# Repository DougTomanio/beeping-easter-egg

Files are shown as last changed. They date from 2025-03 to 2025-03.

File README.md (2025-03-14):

# Beeping Easter Egg 🥚🔊

<p float="center">
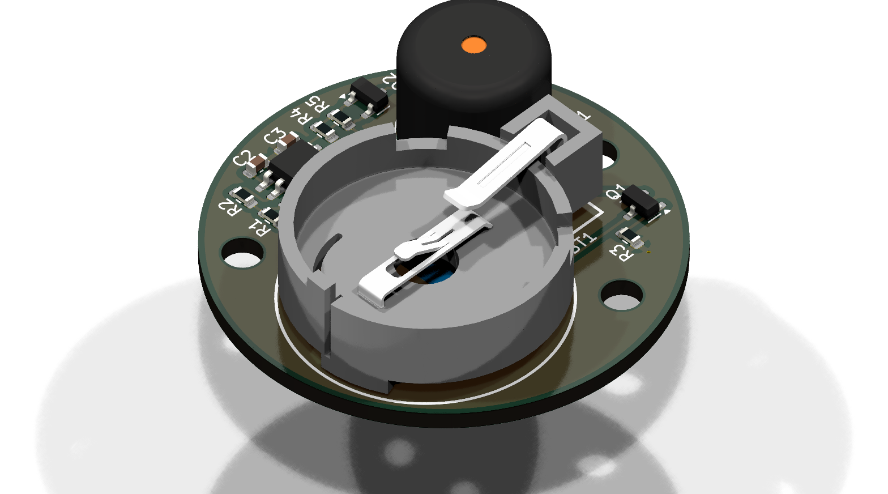
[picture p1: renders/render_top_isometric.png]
  
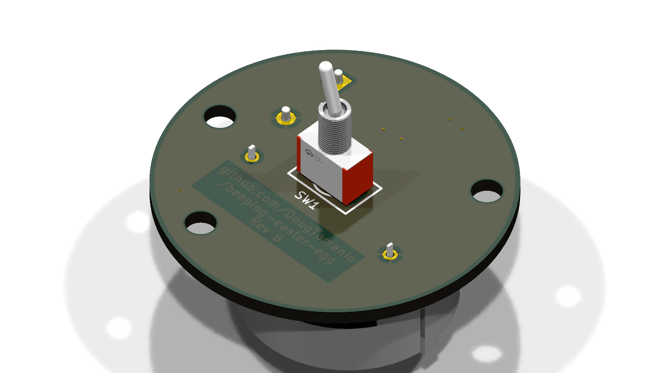
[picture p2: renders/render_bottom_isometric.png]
  
</p>
<p float="center">
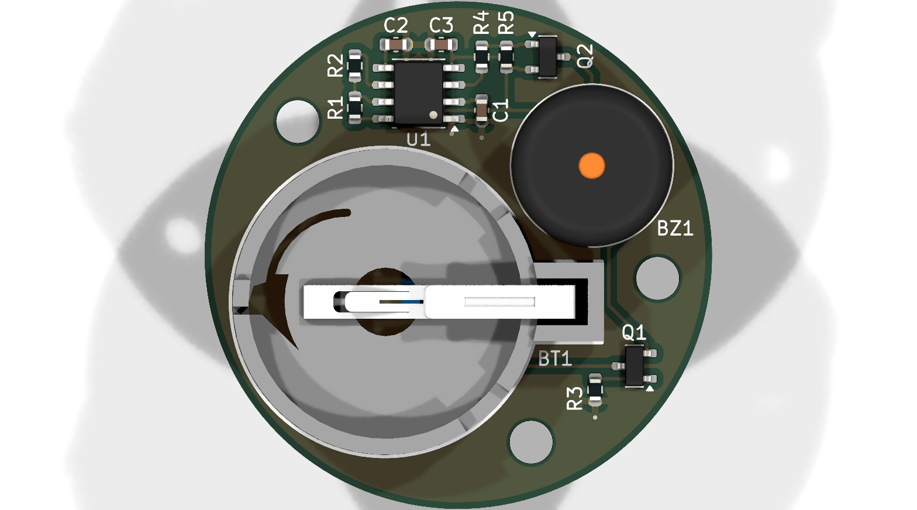
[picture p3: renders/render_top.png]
   
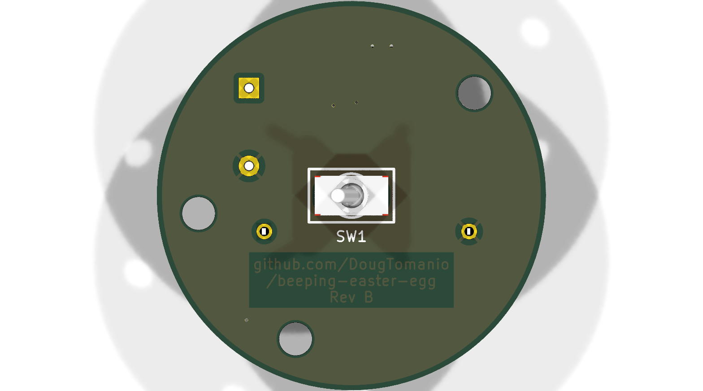
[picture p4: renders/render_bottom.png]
  
</p>


## Generate fabrication files
```
docker run --rm -v ${PWD}:/app -e COLS=5 -e ROWS=5 kicad/kicad:9.0 bash /app/scripts/generate-fabrication-files.sh
```

## Generate render pngs and schematic svg
```
docker run --rm -v ${PWD}:/app kicad/kicad:9.0 bash /app/scripts/generate-renders-for-readme.sh
```

## KiCad plugins / tools / scripts
* https://github.com/yaqwsx/KiKit
* https://github.com/uPesy/easyeda2kicad.py

## Component calculations
[component-calculations.md](component-calculations.md)

## TODO
* Try KiCad jobset to replace generate-renders-for-readme.sh
* Use official KiKit docker image once it supports KiCad 9
* Find a proper 3D model for switch

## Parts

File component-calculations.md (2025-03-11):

## Component value calculations for the 555 astable circuit

The formulas for our 555 astable circuit's timing are

time high $`t_1 = ln(2) * (R_1 + R_2) * C`$\
time low $`t_2 = ln(2) * R_1 * C`$\
period $`T = t_1 + t_2`$\
frequency $`f = \frac{1}{T}`$\
duty cycle $`D = \frac{t_1}{T}`$

Putting $`R_1`$ and $`R_2`$ in terms of $`f`$, $`D`$, and $`C`$ we get

$`R_1 = \frac{2D - 1}{ln(2) * f * C}`$\
$`R_2 = \frac{1 - D}{ln(2) * f * C}`$

We want a beep of $`1.5Hz`$ with a $`25\%`$ duty cycle. Since our buzzer will sound when the signal from the 555 is low, our circuit will need the opposite duty cycle. We choose a reasonably small standard value for $`C`$ to keep current/power low.

$`f = 1.5 Hz`$\
$`D = 100\% - 25\% = 75\%`$\
$`C = 47 nF`$

So

$`R_1 = \frac{2D - 1}{ln(2) * f * C} = \frac{2 * 75\% - 1}{ln(2) * 1.5 Hz * 47 nF} = 10.2319 M\Omega`$\
$`R_2 = \frac{1 - D}{ln(2) * f * C} = \frac{1 - 75\%}{ln(2) * 1.5 Hz * 47 nF} = 5.1159 M\Omega`$

Since there is no need for this timing to be exact, we choose the closest standard values for $`R_1`$ and $`R_2`$, giving us our component values of 

$`R_1 = 10 M\Omega`$\
$`R_2 = 5.1 M\Omega`$\
$`C = 47 nF`$

So our actual frequency and duty cycle will be

$`t_1 = ln(2) * (R_1 + R_2) * C = ln(2) * (10 M\Omega + 5.1 M\Omega) * 47 nF = 0.49 s`$\
$`t_2 = ln(2) * R_2 * C = ln(2) * 5.1 M\Omega * 47 nF = 0.17 s`$\
$`T = t_1 + t_2 = 0.49 s + 0.17 s = 0.66 s`$\
$`f = \frac{1}{T} = \frac{1}{0.66 s} = 1.52 Hz`$\
$`D = \frac{t_1}{T} = \frac{0.49 s}{0.66 s} = 74\%`$

Giving us a beep of $`1.52Hz`$ with a $`26\%`$ duty cycle. That is a $`0.17`$ second long beep every $`0.66`$ seconds.

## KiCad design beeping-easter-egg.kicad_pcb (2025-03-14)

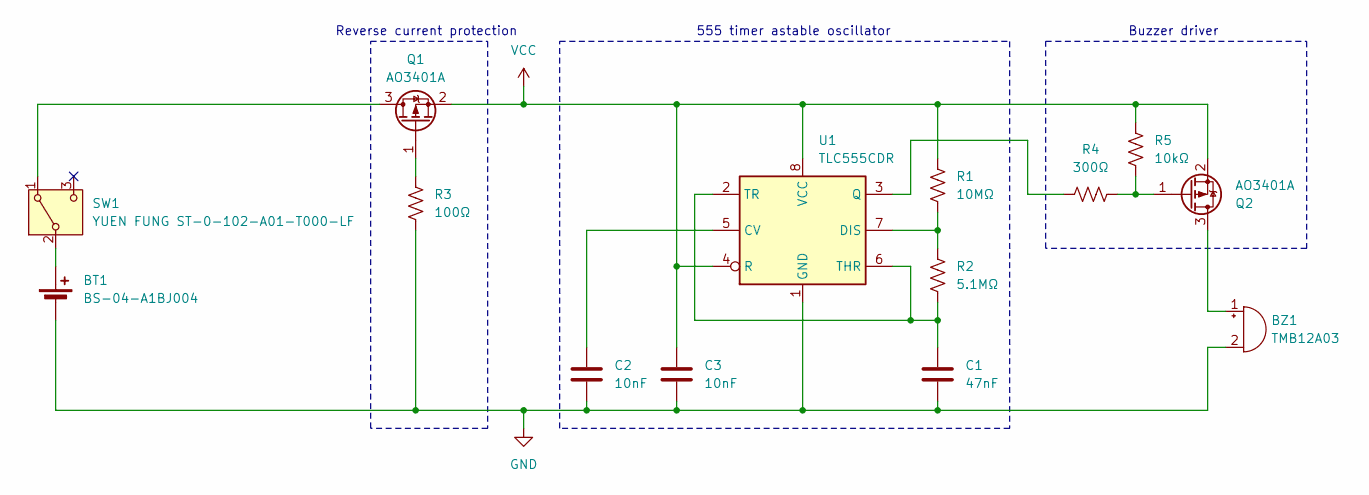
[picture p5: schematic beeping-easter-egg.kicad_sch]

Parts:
BT1: BS-04-A1BJ004; BAT-TH_BS-04-A1BJ004; LCSC C964750
BZ1: TMB12A03; Buzzer_12x9.5RM7.6; LCSC C96222
C1: 47nF; C_0603_1608Metric; LCSC C1622
C2, C3: 10nF; C_0603_1608Metric; LCSC C57112
Q1, Q2: AO3401A; SOT-23; LCSC C15127
R1: 10MΩ; R_0603_1608Metric; LCSC C7250
R2: 5.1MΩ; R_0603_1608Metric; LCSC C13320
R3: 100Ω; R_0603_1608Metric; LCSC C22775
R4: 300Ω; R_0603_1608Metric; LCSC C23025
R5: 10kΩ; R_0603_1608Metric; LCSC C25804
SW1: YUEN FUNG ST-0-102-A01-T000-LF; SW-TH_3P-L8.3-W5.2-P2.54_ST-0-102-A01-T000; LCSC C1788487
U1: TLC555CDR; SOIC-8_3.9x4.9mm_P1.27mm; LCSC C6986

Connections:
GND: BT1.2 (-), BZ1.2 (-), C1.2, C2.2, C3.2, R3.2, U1.1 (GND)
unnamed: BT1.1 (+), SW1.2 (B)
unnamed: BZ1.1 (+), Q2.3 (D)
unnamed: Q1.3 (D), SW1.1 (A)
unnamed: Q1.1 (G), R3.1
unnamed: Q2.1 (G), R4.2, R5.2
unnamed: C2.1, U1.5 (CV)
unnamed: R1.2, R2.1, U1.7 (DIS)
unnamed: R4.1, U1.3 (Q)
unnamed: C1.1, R2.2, U1.2 (TR), U1.6 (THR)
VCC: C3.1, Q1.2 (S), Q2.2 (S), R1.1, R5.1, U1.4 (R), U1.8 (VCC)

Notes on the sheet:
Reverse current protection
Buzzer driver
555 timer astable oscillator

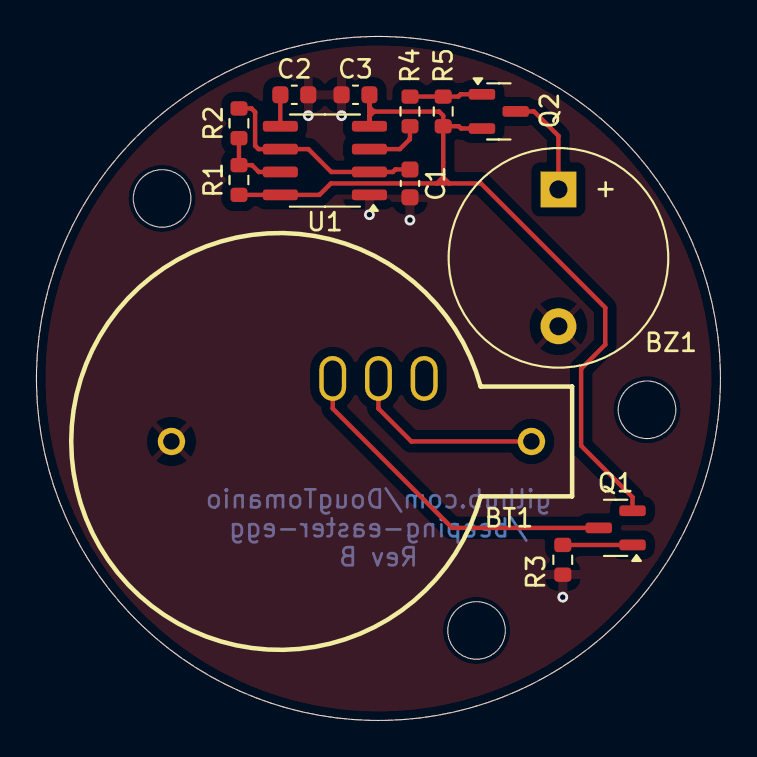
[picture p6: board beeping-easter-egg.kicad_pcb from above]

Board: 2 copper layers, 38.0 x 38.0 mm, 14 parts (1 on the bottom side), 11 nets.

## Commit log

2025-03-08 Change buzzer driver to pnp, remove 555 inverting buffer.
    Add reverse polarity protection.
    Add custom footprint for battery holder.
    [beeping-easter-egg.kicad_sch]
2025-03-08 update pcb from schematic
    [beeping-easter-egg.kicad_pcb]
2025-03-08 switch from bjts to mosfets
    [beeping-easter-egg.kicad_pcb, beeping-easter-egg.kicad_sch]
2025-03-08 Switch to SMD footprints. Add filter cap to reset.
    [beeping-easter-egg.kicad_pcb, beeping-easter-egg.kicad_sch]
2025-03-08 Change 555 R and C values to reduce current. Ratio and thus timing stays the same. Some component renaming.
    [beeping-easter-egg-CuBottom.gbr, beeping-easter-egg-CuTop.gbr, beeping-easter-egg-EdgeCuts.gbr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]
2025-03-08 Change 555 R and C values to reduce current. Ratio and thus timing stays the same. Some component renaming. Add LCSC field.
    [beeping-easter-egg-CuBottom.gbr, beeping-easter-egg-CuTop.gbr, beeping-easter-egg-EdgeCuts.gbr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]
2025-03-08 Revert commit of generated jlcpcb files
    This partially reverts commit 3e110100dbd27910e5bf91a673afcf49d5367dce.
    [beeping-easter-egg-CuBottom.gbr, beeping-easter-egg-CuTop.gbr, beeping-easter-egg-EdgeCuts.gbr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]
2025-03-08 Revert commit of generated jlcpcb files
    (cherry picked from commit 4657ed03a1a465b8d6b939ffa78540d57d0fadf1)
    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
    [beeping-easter-egg-CuBottom.gbr, beeping-easter-egg-CuTop.gbr, beeping-easter-egg-EdgeCuts.gbr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]
2025-03-08 Adjust R1 value to nearest commonly availably value. Add LCSC number for battery holder.
    [beeping-easter-egg.kicad_pcb, beeping-easter-egg.kicad_sch]
2025-03-08 Convert to kicad version 9. Add LCSC part numbers.
    [beeping-easter-egg.kicad_pcb, beeping-easter-egg.kicad_sch]
2025-03-08 some schematic cleanup
    [beeping-easter-egg.kicad_sch]
2025-03-08 Add footprints for battery holder and switch using easyeda2kicad script.
    [beeping-easter-egg.kicad_sch]
2025-03-08 Place components. Add 3D model for switch.
    [beeping-easter-egg.kicad_pcb]
2025-03-08 Improved placement of some ground vias
    [beeping-easter-egg.kicad_pcb]
2025-03-08 Clean up fab layers. Update some component info.
    [beeping-easter-egg.kicad_pcb, beeping-easter-egg.kicad_sch]
2025-03-08 Add readme. Add exported schematic and renders for readme.
2025-03-08 Resize schematic to A5. Add title to schematic.
    [beeping-easter-egg.kicad_sch]
2025-03-08 Change track width to 0.25mm
    [beeping-easter-egg.kicad_pcb]
2025-03-08 Add tooling holes per jlcpcb's spec
    [beeping-easter-egg.kicad_pcb]
2025-03-08 Add JLCPCB order number placeholder per jlcpcb spec
    [beeping-easter-egg.kicad_pcb]
2025-03-08 Add 3rd tooling hole. Remove unused custom footprint for tooling hole.
    [beeping-easter-egg.kicad_pcb]
2025-03-08 Fix DRC issues with tooling holes
    [beeping-easter-egg.kicad_pcb]
2025-03-08 Add project label to silkscreen
    [beeping-easter-egg.kicad_pcb]
2025-03-08 Ran "Cleanup Tracks & Vias" tool
    [beeping-easter-egg.kicad_pcb]
2025-03-08 Fix missing ref DRC issue with tooling holes
    [beeping-easter-egg.kicad_pcb, beeping-easter-egg.kicad_sch]
2025-03-08 Change title silkscreen style to knockout
    [beeping-easter-egg.kicad_pcb]
2025-03-08 Reduce text size of JLCPCB order number placeholder
    [beeping-easter-egg.kicad_pcb]
2025-03-08 Move component info generated by easyeda2kicad to local project library.
    [beeping-easter-egg.kicad_pcb, beeping-easter-egg.kicad_sch]
2025-03-08 Fix DRC issue with tooling holes
    [beeping-easter-egg.kicad_pcb]
2025-03-08 Clean up ground plane zone border
    [beeping-easter-egg.kicad_pcb]
2025-03-09 Make sure we are running in the kicad docker container before doing kikit setup
2025-03-09 Corrections for JLCPCB component rotation using KiKit "JLCPCB_CORRECTION" property
    [beeping-easter-egg.kicad_sch]
2025-03-09 Use JLCPCB spec 3.85mm offset for fiducials. Switch to frame style rails. Switch to 3 fiducials for non symmetrical pattern.
2025-03-09 Set solder mask clearances per jlcpcb spec
    [beeping-easter-egg.kicad_pcb]
2025-03-09 Update pcb from schematic to pull in missing JLCPCB_CORRECTION fields
    [beeping-easter-egg.kicad_pcb]
2025-03-09 Remove tooling holes. They are added to the panelization frame instead.
    [beeping-easter-egg.kicad_pcb, beeping-easter-egg.kicad_sch]
2025-03-09 Remove jlc order number placeholder. It is added to the panelization frame instead.
    [beeping-easter-egg.kicad_pcb]
2025-03-09 Move label to back copper. Add Rev number.
    [beeping-easter-egg.kicad_pcb, beeping-easter-egg.kicad_sch]
2025-03-09 Remove reference to unused KiCad plugin. Using KiKit to generate fab files instead.
2025-03-09 Hide JLCPCB_CORRECTION field on schematic.
    [beeping-easter-egg.kicad_sch]
2025-03-09 Set title
    [beeping-easter-egg.kicad_pcb, beeping-easter-egg.kicad_sch]
2025-03-09 Use jlcpcb spec for tooling holes. Changed panelization frame type to tightframe.
2025-03-11 Update component values to reflect corrected timing calculations
    [beeping-easter-egg.kicad_pcb, beeping-easter-egg.kicad_sch]
2025-03-11 update rev
    [beeping-easter-egg.kicad_pcb, beeping-easter-egg.kicad_sch]
2025-03-12 Add cover panel
    [beeping-easter-egg.kicad_pcb]
2025-03-12 Mark mounting holes as excluded from schematic.
    [beeping-easter-egg.kicad_pcb]
2025-03-12 Add another mounting hole for cover plate. Move Q1 and R3 to make room for new mounting hole.
    [beeping-easter-egg.kicad_pcb]
2025-03-12 Change panelization rows and cols defaults to maximum without incuring large board fees from jlc.
2025-03-14 Separate cover into separate kicad_pcb file.
    [beeping-easter-egg-cover.kicad_pcb, beeping-easter-egg.kicad_pcb]
2025-03-14 Update title
    [beeping-easter-egg.kicad_pcb, beeping-easter-egg.kicad_sch]
2025-03-14 Adjust thermal reliefs for through-hole components
    [beeping-easter-egg.kicad_pcb]
